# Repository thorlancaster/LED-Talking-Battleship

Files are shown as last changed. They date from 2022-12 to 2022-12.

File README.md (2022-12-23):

# LED-Talking-Battleship
Talking Battleship implemented on a 12x12 LED grid with an ATMega328 processor

This project is composed of:
* A Control PCB that contains the main circuitry and power supplies
* A LED display PCB that drives an 12x12 grid of RGB LEDs. You'll need to make 4 of these.
* Code to run the above boards
* A compiled audio file you'll need to write to the SPI Flash chip for audio functionality
 (If you leave the flash chip blank, the game will not play audio)

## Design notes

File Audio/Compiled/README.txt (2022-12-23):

Battleship.tatx should be copied byte for byte onto the SPI flash chip attached to the ATMega328.

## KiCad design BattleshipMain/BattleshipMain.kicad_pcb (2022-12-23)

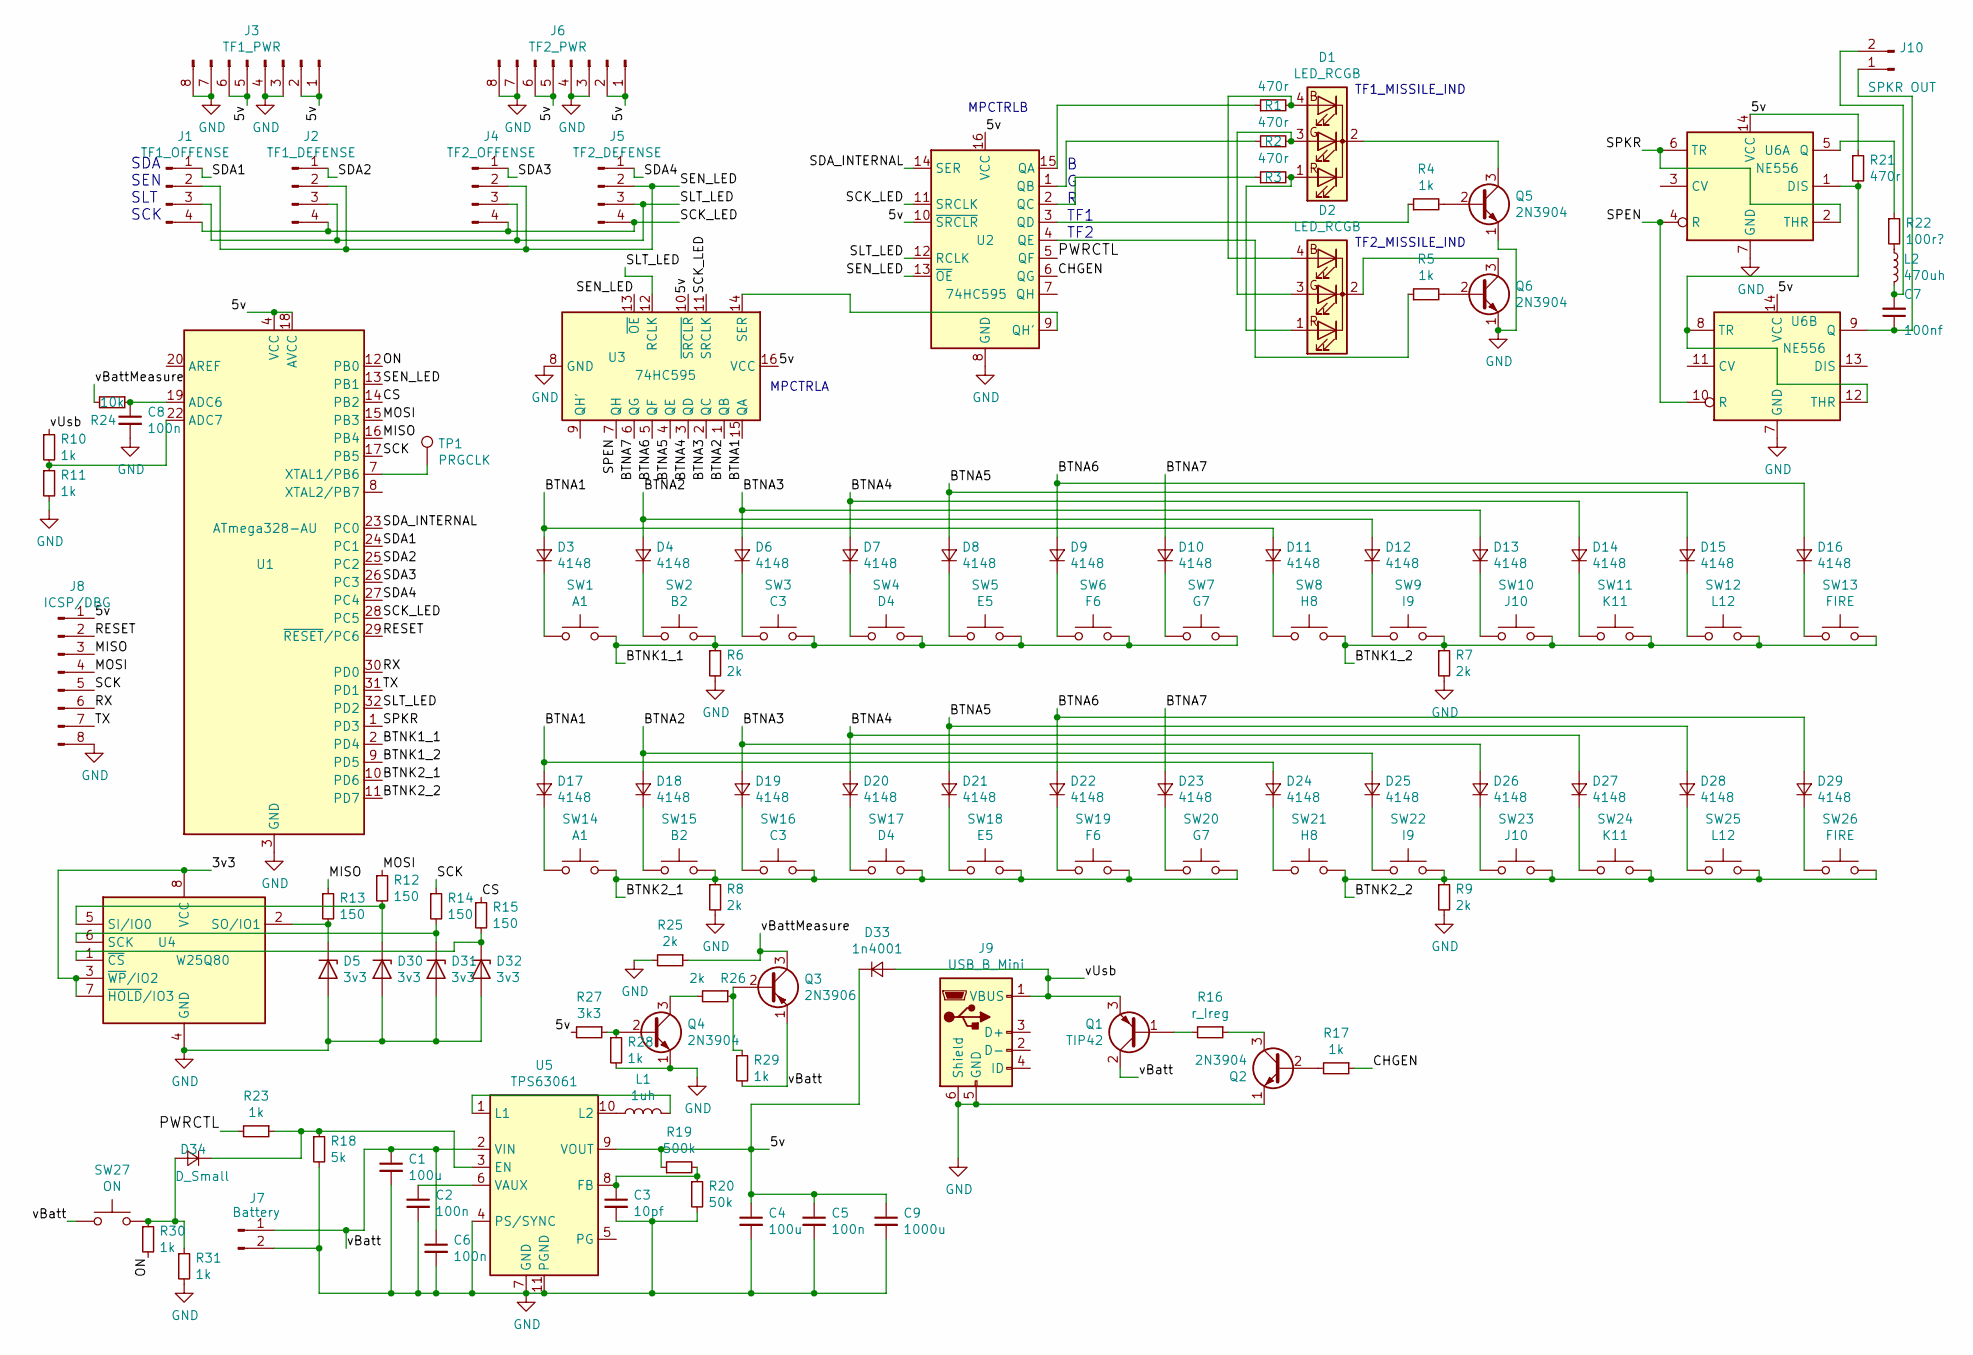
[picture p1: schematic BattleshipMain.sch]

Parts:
C1, C4: 100u; CP_Radial_D10.0mm_P2.50mm
C2, C5, C6, C8: 100n; C_0805_2012Metric
C3: 10pf; C_0805_2012Metric
C7: 100nf; C_0805_2012Metric
C9: 1000u; CP_Radial_D10.0mm_P7.50mm
D1, D2: LED_RCGB; LED_D5.0mm-4_RGB
D3, D4, D6, D7, D8, D9, D10, D11, D12, D13, D14, D15, D16, D17, D18, D19, D20, D21, D22, D23, D24, D25, D26, D27, D28, D29: 4148; D_DO-34_SOD68_P7.62mm_Horizontal
D5, D30, D31, D32: 3v3; D_DO-34_SOD68_P7.62mm_Horizontal
D33: 1n4001; D_DO-15_P10.16mm_Horizontal
D34: D_Small; D_DO-15_P10.16mm_Horizontal
J1: TF1_OFFENSE; PinHeader_1x04_P2.54mm_Vertical
J2: TF1_DEFENSE; PinHeader_1x04_P2.54mm_Vertical
J3: TF1_PWR; PinHeader_1x08_P2.54mm_Vertical
J4: TF2_OFFENSE; PinHeader_1x04_P2.54mm_Vertical
J5: TF2_DEFENSE; PinHeader_1x04_P2.54mm_Vertical
J6: TF2_PWR; PinHeader_1x08_P2.54mm_Vertical
J7: Battery; PinHeader_1x02_P2.54mm_Vertical
J8: ICSP/DBG; PinHeader_1x08_P2.54mm_Vertical
J9: USB_B_Mini; USB_Mini-B_Lumberg_2486_01_Horizontal
J10: SPKR OUT; PinHeader_1x02_P2.54mm_Vertical
L1: 1uh; L_Bourns-SRR1005
L2: 470uh; R_Axial_DIN0204_L3.6mm_D1.6mm_P7.62mm_Horizontal
Q1: TIP42; TO-220-3_Vertical
Q2, Q4, Q5, Q6: 2N3904; TO-92_Inline
Q3: 2N3906; TO-92_Inline
R1, R2, R3, R21: 470r; R_Axial_DIN0204_L3.6mm_D1.6mm_P7.62mm_Horizontal
R4, R5, R10, R11, R17, R23, R28, R29, R30, R31: 1k; R_Axial_DIN0207_L6.3mm_D2.5mm_P7.62mm_Horizontal
R6, R7, R8, R9, R25, R26: 2k; R_Axial_DIN0207_L6.3mm_D2.5mm_P7.62mm_Horizontal
R12, R13, R14, R15: 150; R_Axial_DIN0204_L3.6mm_D1.6mm_P7.62mm_Horizontal
R16: r_Ireg; R_Axial_DIN0207_L6.3mm_D2.5mm_P7.62mm_Horizontal
R18: 5k; R_Axial_DIN0207_L6.3mm_D2.5mm_P7.62mm_Horizontal
R19: 500k; R_Axial_DIN0207_L6.3mm_D2.5mm_P7.62mm_Horizontal
R20: 50k; R_Axial_DIN0207_L6.3mm_D2.5mm_P7.62mm_Horizontal
R22: 100r?; R_Axial_DIN0207_L6.3mm_D2.5mm_P7.62mm_Horizontal
R24: 10k; R_Axial_DIN0207_L6.3mm_D2.5mm_P7.62mm_Horizontal
R27: 3k3; R_Axial_DIN0207_L6.3mm_D2.5mm_P7.62mm_Horizontal
SW1, SW14: A1; Push_E-Switch_KS01Q01_RubberPad
SW2, SW15: B2; Push_E-Switch_KS01Q01_RubberPad
SW3, SW16: C3; Push_E-Switch_KS01Q01_RubberPad
SW4, SW17: D4; Push_E-Switch_KS01Q01_RubberPad
SW5, SW18: E5; Push_E-Switch_KS01Q01_RubberPad
SW6, SW19: F6; Push_E-Switch_KS01Q01_RubberPad
SW7, SW20: G7; Push_E-Switch_KS01Q01_RubberPad
SW8, SW21: H8; Push_E-Switch_KS01Q01_RubberPad
SW9, SW22: I9; Push_E-Switch_KS01Q01_RubberPad
SW10, SW23: J10; Push_E-Switch_KS01Q01_RubberPad
SW11, SW24: K11; Push_E-Switch_KS01Q01_RubberPad
SW12, SW25: L12; Push_E-Switch_KS01Q01_RubberPad
SW13, SW26: FIRE; Push_E-Switch_KS01Q01_RubberPad
SW27: ON; Push_E-Switch_KS01Q01_RubberPad
TP1: PRGCLK; TestPoint_Pad_2.5x2.5mm
U1: ATmega328-AU; TQFP-32_7x7mm_P0.8mm
U2, U3: 74HC595; DIP-16_W7.62mm
U4: W25Q80; SOIC-8_3.9x4.9mm_P1.27mm
U5: TPS63061; Texas_S-PWSON-N10_ThermalVias
U6: NE556; DIP-16_W7.62mm

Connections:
/3v3: U4.3 (~WP~/IO2), U4.7 (~HOLD~/IO3), U4.8 (VCC)
/5v: C4.1, C5.1, C9.1, D33.1 (K), J3.1, J3.2, J3.5, J3.6, J6.1, J6.2, J6.5, J6.6, J8.1, R19.1, R21.1, R27.2, U1.4 (VCC), U1.6 (VCC), U1.18 (AVCC), U2.10 (~SRCLR), U2.16 (VCC), U3.10 (~SRCLR), U3.16 (VCC), U5.9 (VOUT), U6.14 (VCC)
/BTNA1: D3.2 (A), D11.2 (A), D17.2 (A), D24.2 (A), U3.15 (QA)
/BTNA2: D4.2 (A), D12.2 (A), D18.2 (A), D25.2 (A), U3.1 (QB)
/BTNA3: D6.2 (A), D13.2 (A), D19.2 (A), D26.2 (A), U3.2 (QC)
/BTNA4: D7.2 (A), D14.2 (A), D20.2 (A), D27.2 (A), U3.3 (QD)
/BTNA5: D8.2 (A), D15.2 (A), D21.2 (A), D28.2 (A), U3.4 (QE)
/BTNA6: D9.2 (A), D16.2 (A), D22.2 (A), D29.2 (A), U3.5 (QF)
/BTNA7: D10.2 (A), D23.2 (A), U3.6 (QG)
/BTNK1_1: R6.1, SW1.2, SW2.2, SW3.2, SW4.2, SW5.2, SW6.2, SW7.2, U1.2 (PD4)
/BTNK1_2: R7.1, SW8.2, SW9.2, SW10.2, SW11.2, SW12.2, SW13.2, U1.9 (PD5)
/BTNK2_1: R8.1, SW14.2, SW15.2, SW16.2, SW17.2, SW18.2, SW19.2, SW20.2, U1.10 (PD6)
/BTNK2_2: R9.1, SW21.2, SW22.2, SW23.2, SW24.2, SW25.2, SW26.2, U1.11 (PD7)
/CS: R15.1, U1.14 (PB2)
/MISO: J8.3, R13.1, U1.16 (PB4)
/MOSI: J8.4, R12.1, U1.15 (PB3)
/ON: R30.2, U1.12 (PB0)
/RESET: J8.2, U1.29 (~RESET~/PC6)
/RX: J8.6, U1.30 (PD0)
/SCK: J8.5, R14.1, U1.17 (PB5)
/SDA1: J1.1, U1.24 (PC1)
/SDA2: J2.1, U1.25 (PC2)
/SDA3: J4.1, U1.26 (PC3)
/SDA4: J5.1, U1.27 (PC4)
/SDA_INTERNAL: U1.23 (PC0), U2.14 (SER)
/SEN_LED: J1.2, J2.2, J4.2, J5.2, U1.13 (PB1), U2.13 (~OE), U3.13 (~OE)
/SPEN: U3.7 (QH), U6.4 (R), U6.10 (R)
/SPKR: U1.1 (PD3), U6.2 (THR), U6.6 (TR)
/TX: J8.7, U1.31 (PD1)
/vBatt: C1.1, C6.1, J7.1, Q1.2 (C), Q3.1 (E), R29.2, SW27.1, U5.2 (VIN)
/vBattMeasure: Q3.3 (C), R24.2, R25.1
/vUsb: D33.2 (A), J9.1 (VBUS), Q1.3 (E), R10.1
GND: C1.2, C2.2, C3.2, C4.2, C5.2, C6.2, C8.2, C9.2, D5.2 (A), D30.2 (A), D31.2 (A), D32.2 (A), J3.3, J3.4, J3.7, J3.8, J6.3, J6.4, J6.7, J6.8, J7.2, J8.8, J9.5 (GND), J9.6 (Shield), Q2.1 (E), Q4.1 (E), Q5.1 (E), Q6.1 (E), R6.2, R7.2, R8.2, R9.2, R11.2, R18.2, R20.2, R25.2, R28.2, R31.2, U1.3 (GND), U1.5 (GND), U1.21 (GND), U2.8 (GND), U3.8 (GND), U4.4 (GND), U5.4 (PS/SYNC), U5.7 (GND), U5.11 (PGND), U6.7 (GND)
unnamed: C2.1, U5.6 (VAUX)
unnamed: C3.1, R19.2, R20.1, U5.8 (FB)
unnamed: C7.1, J10.1, U6.9 (Q)
unnamed: C7.2, J10.2, L2.2
unnamed: C8.1, R24.1, U1.19 (ADC6)
unnamed: D1.1 (RA), D2.1 (RA), R3.2
unnamed: D1.2 (K), Q5.3 (C)
unnamed: D1.3 (GA), D2.3 (GA), R2.2
unnamed: D1.4 (BA), D2.4 (BA), R1.2
unnamed: D2.2 (K), Q6.3 (C)
unnamed: D3.1 (K), SW1.1
unnamed: D4.1 (K), SW2.1
unnamed: D5.1 (K), R13.2, U4.2 (SO/IO1)
unnamed: D6.1 (K), SW3.1
unnamed: D7.1 (K), SW4.1
unnamed: D8.1 (K), SW5.1
unnamed: D9.1 (K), SW6.1
unnamed: D10.1 (K), SW7.1
unnamed: D11.1 (K), SW8.1
unnamed: D12.1 (K), SW9.1
unnamed: D13.1 (K), SW10.1
unnamed: D14.1 (K), SW11.1
unnamed: D15.1 (K), SW12.1
unnamed: D16.1 (K), SW13.1
unnamed: D17.1 (K), SW14.1
unnamed: D18.1 (K), SW15.1
unnamed: D19.1 (K), SW16.1
unnamed: D20.1 (K), SW17.1
unnamed: D21.1 (K), SW18.1
unnamed: D22.1 (K), SW19.1
unnamed: D23.1 (K), SW20.1
unnamed: D24.1 (K), SW21.1
unnamed: D25.1 (K), SW22.1
unnamed: D26.1 (K), SW23.1
unnamed: D27.1 (K), SW24.1
unnamed: D28.1 (K), SW25.1
unnamed: D29.1 (K), SW26.1
unnamed: D30.1 (K), R12.2, U4.5 (SI/IO0)
unnamed: D31.1 (K), R14.2, U4.6 (SCK)
unnamed: D32.1 (K), R15.2, U4.1 (~CS)
unnamed: D34.1 (K), R18.1, R23.1, U5.3 (EN)
unnamed: D34.2 (A), R30.1, R31.1, SW27.2
unnamed: L1.1, U5.10 (L2)
unnamed: L1.2, U5.1 (L1)
unnamed: L2.1, R22.2
unnamed: Q1.1 (B), R16.2
unnamed: Q2.2 (B), R17.2
unnamed: Q2.3 (C), R16.1
unnamed: Q3.2 (B), R26.1, R29.1
unnamed: Q4.2 (B), R27.1, R28.1
unnamed: Q4.3 (C), R26.2
unnamed: Q5.2 (B), R4.2
unnamed: Q6.2 (B), R5.2
unnamed: R1.1, U2.15 (QA)
unnamed: R2.1, U2.1 (QB)
unnamed: R3.1, U2.2 (QC)
unnamed: R4.1, U2.3 (QD)
unnamed: R5.1, U2.4 (QE)
unnamed: R10.2, R11.1, U1.22 (ADC7)
unnamed: R21.2, U6.1 (DIS), U6.8 (TR), U6.12 (THR)
unnamed: R22.1, U6.5 (Q)
unnamed: U2.9 (QH'), U3.14 (SER)

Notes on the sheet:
SDA SEN SLT SCK
TF1_MISSILE_IND
TF2_MISSILE_IND
B G R TF1 TF2
MPCTRLB
MPCTRLA

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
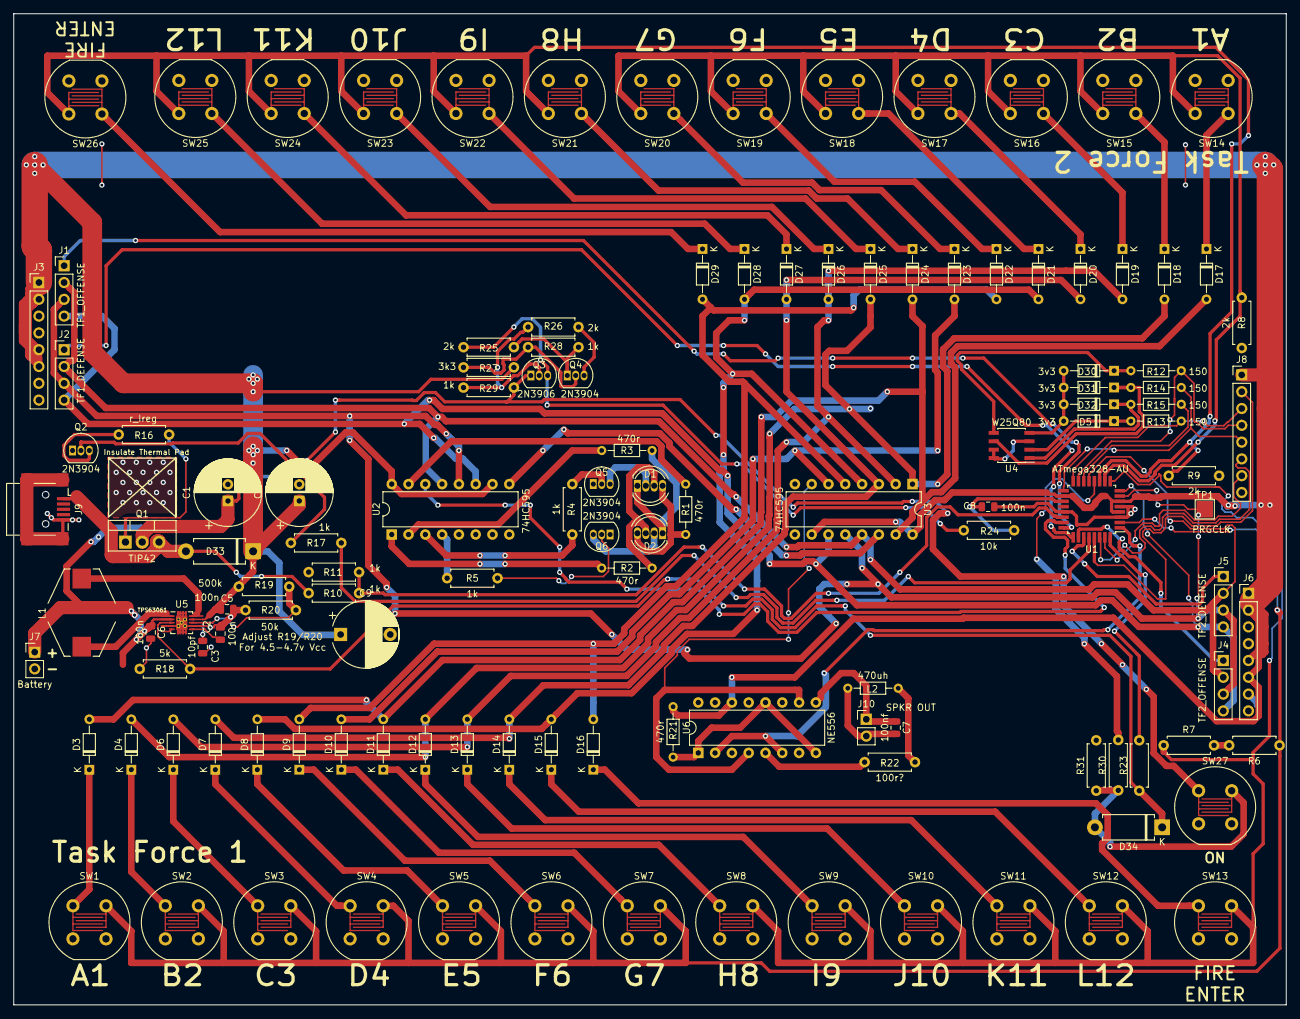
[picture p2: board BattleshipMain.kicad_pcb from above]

Board: 2 copper layers, 192.4 x 149.9 mm, 126 parts (0 on the bottom side), 99 nets.

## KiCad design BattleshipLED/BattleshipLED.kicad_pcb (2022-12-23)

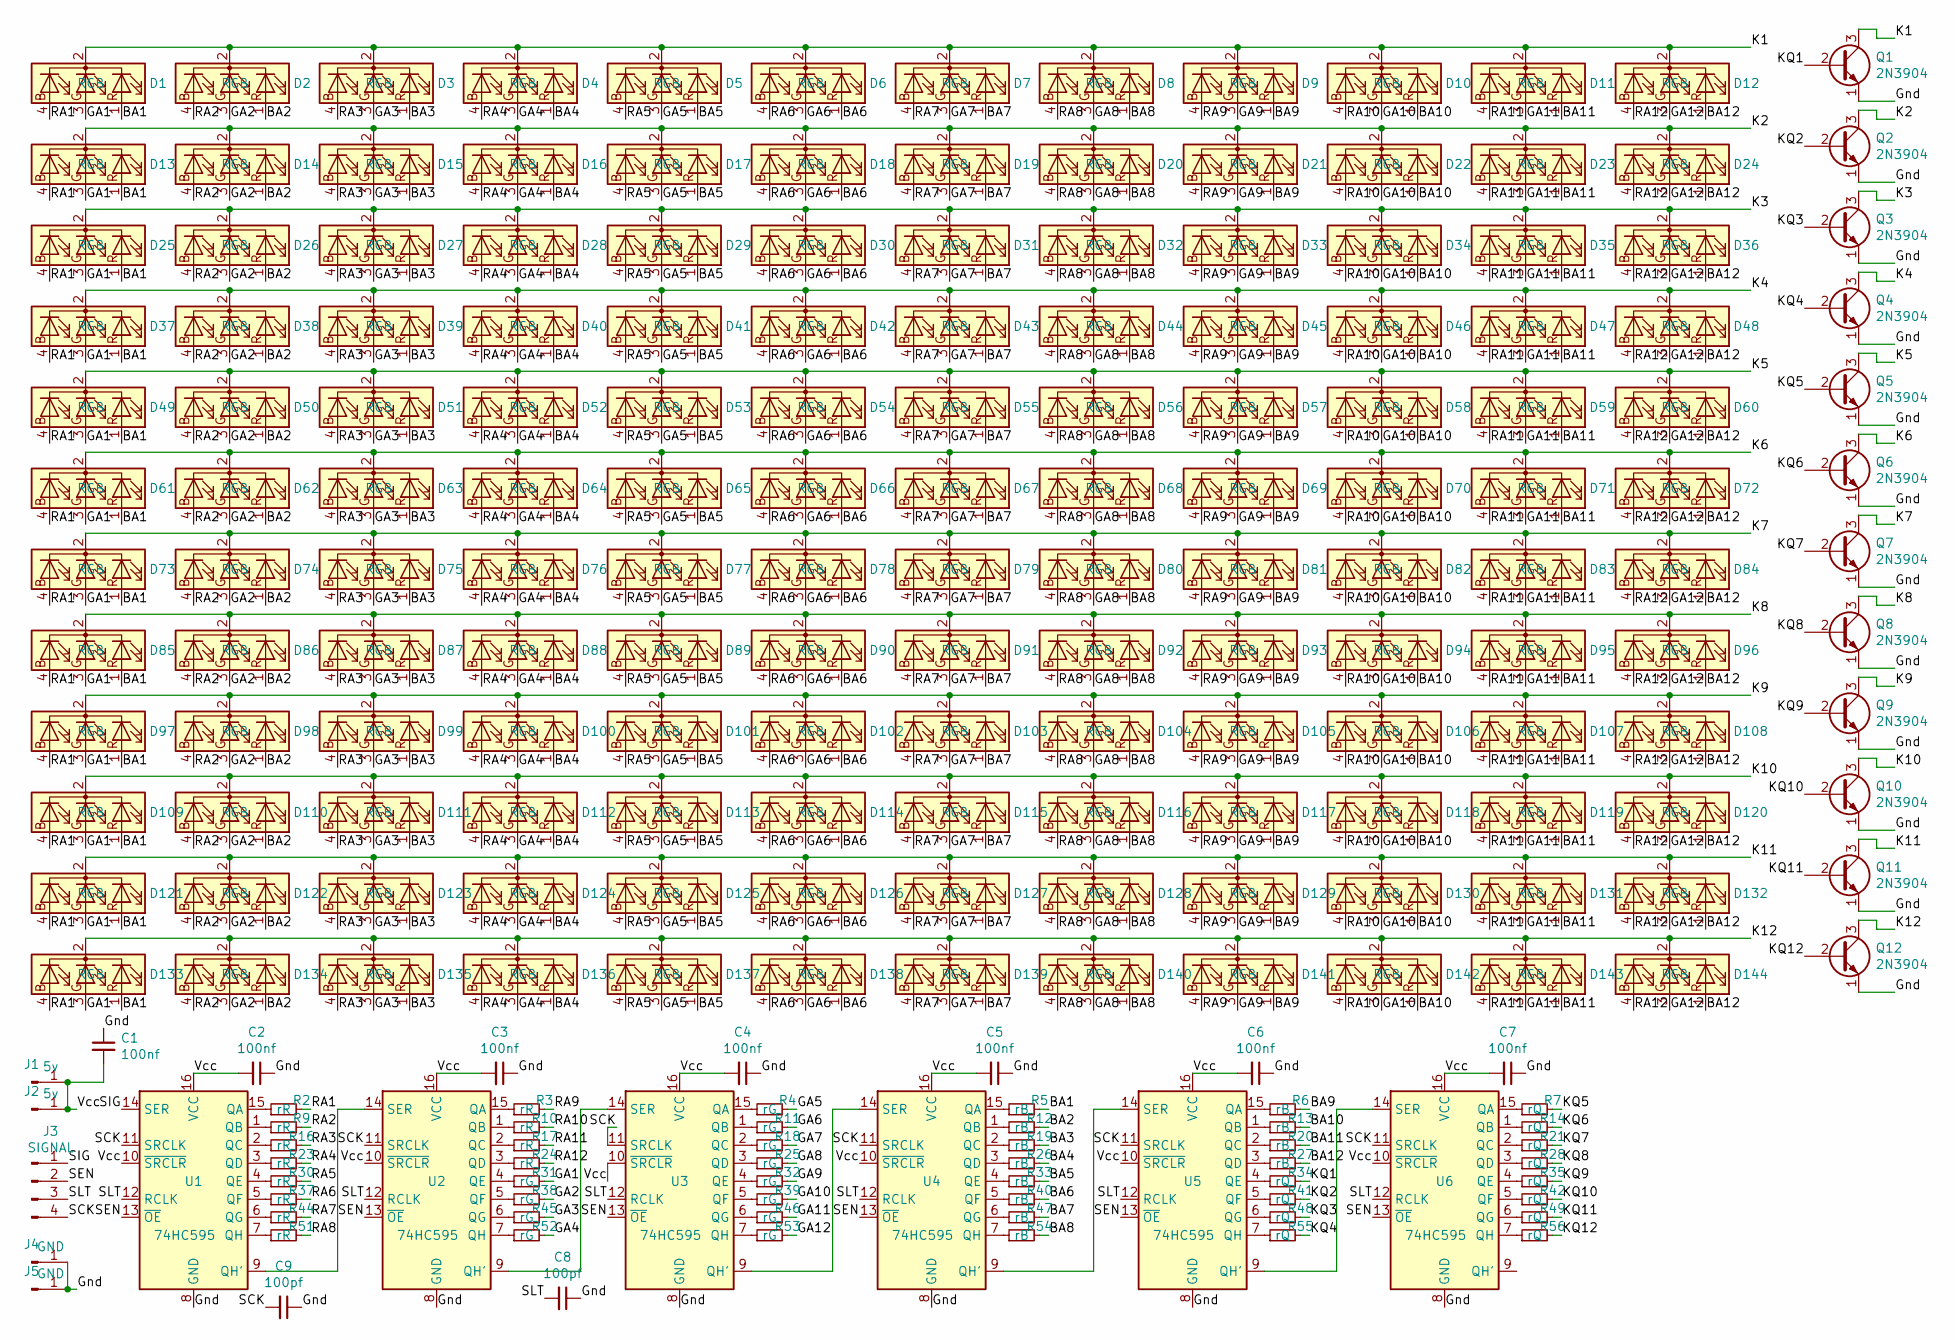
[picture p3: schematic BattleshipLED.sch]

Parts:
C1, C2, C3, C4, C5, C6, C7: 100nf; C_0805_2012Metric
C8, C9: 100pf; C_0805_2012Metric
D1, D2, D3, D4, D5, D6, D7, D8, D9, D10, D11, D12, D13, D14, D15, D16, D17, D18, D19, D20, D21, D22, D23, D24, D25, D26, D27, D28, D29, D30, D31, D32, D33, D34, D35, D36, D37, D38, D39, D40, D41, D42, D43, D44, D45, D46, D47, D48, D49, D50, D51, D52, D53, D54, D55, D56, D57, D58, D59, D60, D61, D62, D63, D64, D65, D66, D67, D68, D69, D70, D71, D72, D73, D74, D75, D76, D77, D78, D79, D80, D81, D82, D83, D84, D85, D86, D87, D88, D89, D90, D91, D92, D93, D94, D95, D96, D97, D98, D99, D100, D101, D102, D103, D104, D105, D106, D107, D108, D109, D110, D111, D112, D113, D114, D115, D116, D117, D118, D119, D120, D121, D122, D123, D124, D125, D126, D127, D128, D129, D130, D131, D132, D133, D134, D135, D136, D137, D138, D139, D140, D141, D142, D143, D144: RGB; LED_D5.0mm-4_RGB
J1, J2: 5v; PinHeader_1x01_P2.54mm_Vertical
J3: SIGNAL; PinHeader_1x04_P2.54mm_Vertical
J4, J5: GND; PinHeader_1x01_P2.54mm_Vertical
Q1, Q2, Q3, Q4, Q5, Q6, Q7, Q8, Q9, Q10, Q11, Q12: 2N3904; TO-92_Inline
R2, R3, R9, R10, R16, R17, R23, R24, R30, R37, R44, R51: rR; R_Axial_DIN0204_L3.6mm_D1.6mm_P7.62mm_Horizontal
R4, R11, R18, R25, R31, R32, R38, R39, R45, R46, R52, R53: rG; R_Axial_DIN0204_L3.6mm_D1.6mm_P7.62mm_Horizontal
R5, R6, R12, R13, R19, R20, R26, R27, R33, R40, R47, R54: rB; R_Axial_DIN0204_L3.6mm_D1.6mm_P7.62mm_Horizontal
R7, R14, R21, R28, R34, R35, R41, R42, R48, R49, R55, R56: rQ; R_Axial_DIN0204_L3.6mm_D1.6mm_P7.62mm_Horizontal
U1, U2, U3, U4, U5, U6: 74HC595; DIP-16_W7.62mm

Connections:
/BA1: D1.1 (RA), D13.1 (RA), D25.1 (RA), D37.1 (RA), D49.1 (RA), D61.1 (RA), D73.1 (RA), D85.1 (RA), D97.1 (RA), D109.1 (RA), D121.1 (RA), D133.1 (RA), R5.2
/BA2: D2.1 (RA), D14.1 (RA), D26.1 (RA), D38.1 (RA), D50.1 (RA), D62.1 (RA), D74.1 (RA), D86.1 (RA), D98.1 (RA), D110.1 (RA), D122.1 (RA), D134.1 (RA), R12.2
/BA3: D3.1 (RA), D15.1 (RA), D27.1 (RA), D39.1 (RA), D51.1 (RA), D63.1 (RA), D75.1 (RA), D87.1 (RA), D99.1 (RA), D111.1 (RA), D123.1 (RA), D135.1 (RA), R19.2
/BA4: D4.1 (RA), D16.1 (RA), D28.1 (RA), D40.1 (RA), D52.1 (RA), D64.1 (RA), D76.1 (RA), D88.1 (RA), D100.1 (RA), D112.1 (RA), D124.1 (RA), D136.1 (RA), R26.2
/BA5: D5.1 (RA), D17.1 (RA), D29.1 (RA), D41.1 (RA), D53.1 (RA), D65.1 (RA), D77.1 (RA), D89.1 (RA), D101.1 (RA), D113.1 (RA), D125.1 (RA), D137.1 (RA), R33.2
/BA6: D6.1 (RA), D18.1 (RA), D30.1 (RA), D42.1 (RA), D54.1 (RA), D66.1 (RA), D78.1 (RA), D90.1 (RA), D102.1 (RA), D114.1 (RA), D126.1 (RA), D138.1 (RA), R40.2
/BA7: D7.1 (RA), D19.1 (RA), D31.1 (RA), D43.1 (RA), D55.1 (RA), D67.1 (RA), D79.1 (RA), D91.1 (RA), D103.1 (RA), D115.1 (RA), D127.1 (RA), D139.1 (RA), R47.2
/BA8: D8.1 (RA), D20.1 (RA), D32.1 (RA), D44.1 (RA), D56.1 (RA), D68.1 (RA), D80.1 (RA), D92.1 (RA), D104.1 (RA), D116.1 (RA), D128.1 (RA), D140.1 (RA), R54.2
/BA9: D9.1 (RA), D21.1 (RA), D33.1 (RA), D45.1 (RA), D57.1 (RA), D69.1 (RA), D81.1 (RA), D93.1 (RA), D105.1 (RA), D117.1 (RA), D129.1 (RA), D141.1 (RA), R6.2
/BA10: D10.1 (RA), D22.1 (RA), D34.1 (RA), D46.1 (RA), D58.1 (RA), D70.1 (RA), D82.1 (RA), D94.1 (RA), D106.1 (RA), D118.1 (RA), D130.1 (RA), D142.1 (RA), R13.2
/BA11: D11.1 (RA), D23.1 (RA), D35.1 (RA), D47.1 (RA), D59.1 (RA), D71.1 (RA), D83.1 (RA), D95.1 (RA), D107.1 (RA), D119.1 (RA), D131.1 (RA), D143.1 (RA), R20.2
/BA12: D12.1 (RA), D24.1 (RA), D36.1 (RA), D48.1 (RA), D60.1 (RA), D72.1 (RA), D84.1 (RA), D96.1 (RA), D108.1 (RA), D120.1 (RA), D132.1 (RA), D144.1 (RA), R27.2
/GA1: D1.3 (GA), D13.3 (GA), D25.3 (GA), D37.3 (GA), D49.3 (GA), D61.3 (GA), D73.3 (GA), D85.3 (GA), D97.3 (GA), D109.3 (GA), D121.3 (GA), D133.3 (GA), R31.2
/GA2: D2.3 (GA), D14.3 (GA), D26.3 (GA), D38.3 (GA), D50.3 (GA), D62.3 (GA), D74.3 (GA), D86.3 (GA), D98.3 (GA), D110.3 (GA), D122.3 (GA), D134.3 (GA), R38.2
/GA3: D3.3 (GA), D15.3 (GA), D27.3 (GA), D39.3 (GA), D51.3 (GA), D63.3 (GA), D75.3 (GA), D87.3 (GA), D99.3 (GA), D111.3 (GA), D123.3 (GA), D135.3 (GA), R45.2
/GA4: D4.3 (GA), D16.3 (GA), D28.3 (GA), D40.3 (GA), D52.3 (GA), D64.3 (GA), D76.3 (GA), D88.3 (GA), D100.3 (GA), D112.3 (GA), D124.3 (GA), D136.3 (GA), R52.2
/GA5: D5.3 (GA), D17.3 (GA), D29.3 (GA), D41.3 (GA), D53.3 (GA), D65.3 (GA), D77.3 (GA), D89.3 (GA), D101.3 (GA), D113.3 (GA), D125.3 (GA), D137.3 (GA), R4.2
/GA6: D6.3 (GA), D18.3 (GA), D30.3 (GA), D42.3 (GA), D54.3 (GA), D66.3 (GA), D78.3 (GA), D90.3 (GA), D102.3 (GA), D114.3 (GA), D126.3 (GA), D138.3 (GA), R11.2
/GA7: D7.3 (GA), D19.3 (GA), D31.3 (GA), D43.3 (GA), D55.3 (GA), D67.3 (GA), D79.3 (GA), D91.3 (GA), D103.3 (GA), D115.3 (GA), D127.3 (GA), D139.3 (GA), R18.2
/GA8: D8.3 (GA), D20.3 (GA), D32.3 (GA), D44.3 (GA), D56.3 (GA), D68.3 (GA), D80.3 (GA), D92.3 (GA), D104.3 (GA), D116.3 (GA), D128.3 (GA), D140.3 (GA), R25.2
/GA9: D9.3 (GA), D21.3 (GA), D33.3 (GA), D45.3 (GA), D57.3 (GA), D69.3 (GA), D81.3 (GA), D93.3 (GA), D105.3 (GA), D117.3 (GA), D129.3 (GA), D141.3 (GA), R32.2
/GA10: D10.3 (GA), D22.3 (GA), D34.3 (GA), D46.3 (GA), D58.3 (GA), D70.3 (GA), D82.3 (GA), D94.3 (GA), D106.3 (GA), D118.3 (GA), D130.3 (GA), D142.3 (GA), R39.2
/GA11: D11.3 (GA), D23.3 (GA), D35.3 (GA), D47.3 (GA), D59.3 (GA), D71.3 (GA), D83.3 (GA), D95.3 (GA), D107.3 (GA), D119.3 (GA), D131.3 (GA), D143.3 (GA), R46.2
/GA12: D12.3 (GA), D24.3 (GA), D36.3 (GA), D48.3 (GA), D60.3 (GA), D72.3 (GA), D84.3 (GA), D96.3 (GA), D108.3 (GA), D120.3 (GA), D132.3 (GA), D144.3 (GA), R53.2
/Gnd: C1.1, C2.1, C3.1, C4.1, C5.1, C6.1, C7.1, C8.1, C9.1, J4.1, J5.1, Q1.1 (E), Q2.1 (E), Q3.1 (E), Q4.1 (E), Q5.1 (E), Q6.1 (E), Q7.1 (E), Q8.1 (E), Q9.1 (E), Q10.1 (E), Q11.1 (E), Q12.1 (E), U1.8 (GND), U2.8 (GND), U3.8 (GND), U4.8 (GND), U5.8 (GND), U6.8 (GND)
/K1: D1.2 (K), D2.2 (K), D3.2 (K), D4.2 (K), D5.2 (K), D6.2 (K), D7.2 (K), D8.2 (K), D9.2 (K), D10.2 (K), D11.2 (K), D12.2 (K), Q1.3 (C)
/K2: D13.2 (K), D14.2 (K), D15.2 (K), D16.2 (K), D17.2 (K), D18.2 (K), D19.2 (K), D20.2 (K), D21.2 (K), D22.2 (K), D23.2 (K), D24.2 (K), Q2.3 (C)
/K3: D25.2 (K), D26.2 (K), D27.2 (K), D28.2 (K), D29.2 (K), D30.2 (K), D31.2 (K), D32.2 (K), D33.2 (K), D34.2 (K), D35.2 (K), D36.2 (K), Q3.3 (C)
/K4: D37.2 (K), D38.2 (K), D39.2 (K), D40.2 (K), D41.2 (K), D42.2 (K), D43.2 (K), D44.2 (K), D45.2 (K), D46.2 (K), D47.2 (K), D48.2 (K), Q4.3 (C)
/K5: D49.2 (K), D50.2 (K), D51.2 (K), D52.2 (K), D53.2 (K), D54.2 (K), D55.2 (K), D56.2 (K), D57.2 (K), D58.2 (K), D59.2 (K), D60.2 (K), Q5.3 (C)
/K6: D61.2 (K), D62.2 (K), D63.2 (K), D64.2 (K), D65.2 (K), D66.2 (K), D67.2 (K), D68.2 (K), D69.2 (K), D70.2 (K), D71.2 (K), D72.2 (K), Q6.3 (C)
/K7: D73.2 (K), D74.2 (K), D75.2 (K), D76.2 (K), D77.2 (K), D78.2 (K), D79.2 (K), D80.2 (K), D81.2 (K), D82.2 (K), D83.2 (K), D84.2 (K), Q7.3 (C)
/K8: D85.2 (K), D86.2 (K), D87.2 (K), D88.2 (K), D89.2 (K), D90.2 (K), D91.2 (K), D92.2 (K), D93.2 (K), D94.2 (K), D95.2 (K), D96.2 (K), Q8.3 (C)
/K9: D97.2 (K), D98.2 (K), D99.2 (K), D100.2 (K), D101.2 (K), D102.2 (K), D103.2 (K), D104.2 (K), D105.2 (K), D106.2 (K), D107.2 (K), D108.2 (K), Q9.3 (C)
/K10: D109.2 (K), D110.2 (K), D111.2 (K), D112.2 (K), D113.2 (K), D114.2 (K), D115.2 (K), D116.2 (K), D117.2 (K), D118.2 (K), D119.2 (K), D120.2 (K), Q10.3 (C)
/K11: D121.2 (K), D122.2 (K), D123.2 (K), D124.2 (K), D125.2 (K), D126.2 (K), D127.2 (K), D128.2 (K), D129.2 (K), D130.2 (K), D131.2 (K), D132.2 (K), Q11.3 (C)
/K12: D133.2 (K), D134.2 (K), D135.2 (K), D136.2 (K), D137.2 (K), D138.2 (K), D139.2 (K), D140.2 (K), D141.2 (K), D142.2 (K), D143.2 (K), D144.2 (K), Q12.3 (C)
/KQ1: Q1.2 (B), R34.2
/KQ2: Q2.2 (B), R41.2
/KQ3: Q3.2 (B), R48.2
/KQ4: Q4.2 (B), R55.2
/KQ5: Q5.2 (B), R7.2
/KQ6: Q6.2 (B), R14.2
/KQ7: Q7.2 (B), R21.2
/KQ8: Q8.2 (B), R28.2
/KQ9: Q9.2 (B), R35.2
/KQ10: Q10.2 (B), R42.2
/KQ11: Q11.2 (B), R49.2
/KQ12: Q12.2 (B), R56.2
/RA1: D1.4 (BA), D13.4 (BA), D25.4 (BA), D37.4 (BA), D49.4 (BA), D61.4 (BA), D73.4 (BA), D85.4 (BA), D97.4 (BA), D109.4 (BA), D121.4 (BA), D133.4 (BA), R2.2
/RA2: D2.4 (BA), D14.4 (BA), D26.4 (BA), D38.4 (BA), D50.4 (BA), D62.4 (BA), D74.4 (BA), D86.4 (BA), D98.4 (BA), D110.4 (BA), D122.4 (BA), D134.4 (BA), R9.2
/RA3: D3.4 (BA), D15.4 (BA), D27.4 (BA), D39.4 (BA), D51.4 (BA), D63.4 (BA), D75.4 (BA), D87.4 (BA), D99.4 (BA), D111.4 (BA), D123.4 (BA), D135.4 (BA), R16.2
/RA4: D4.4 (BA), D16.4 (BA), D28.4 (BA), D40.4 (BA), D52.4 (BA), D64.4 (BA), D76.4 (BA), D88.4 (BA), D100.4 (BA), D112.4 (BA), D124.4 (BA), D136.4 (BA), R23.2
/RA5: D5.4 (BA), D17.4 (BA), D29.4 (BA), D41.4 (BA), D53.4 (BA), D65.4 (BA), D77.4 (BA), D89.4 (BA), D101.4 (BA), D113.4 (BA), D125.4 (BA), D137.4 (BA), R30.2
/RA6: D6.4 (BA), D18.4 (BA), D30.4 (BA), D42.4 (BA), D54.4 (BA), D66.4 (BA), D78.4 (BA), D90.4 (BA), D102.4 (BA), D114.4 (BA), D126.4 (BA), D138.4 (BA), R37.2
/RA7: D7.4 (BA), D19.4 (BA), D31.4 (BA), D43.4 (BA), D55.4 (BA), D67.4 (BA), D79.4 (BA), D91.4 (BA), D103.4 (BA), D115.4 (BA), D127.4 (BA), D139.4 (BA), R44.2
/RA8: D8.4 (BA), D20.4 (BA), D32.4 (BA), D44.4 (BA), D56.4 (BA), D68.4 (BA), D80.4 (BA), D92.4 (BA), D104.4 (BA), D116.4 (BA), D128.4 (BA), D140.4 (BA), R51.2
/RA9: D9.4 (BA), D21.4 (BA), D33.4 (BA), D45.4 (BA), D57.4 (BA), D69.4 (BA), D81.4 (BA), D93.4 (BA), D105.4 (BA), D117.4 (BA), D129.4 (BA), D141.4 (BA), R3.2
/RA10: D10.4 (BA), D22.4 (BA), D34.4 (BA), D46.4 (BA), D58.4 (BA), D70.4 (BA), D82.4 (BA), D94.4 (BA), D106.4 (BA), D118.4 (BA), D130.4 (BA), D142.4 (BA), R10.2
/RA11: D11.4 (BA), D23.4 (BA), D35.4 (BA), D47.4 (BA), D59.4 (BA), D71.4 (BA), D83.4 (BA), D95.4 (BA), D107.4 (BA), D119.4 (BA), D131.4 (BA), D143.4 (BA), R17.2
/RA12: D12.4 (BA), D24.4 (BA), D36.4 (BA), D48.4 (BA), D60.4 (BA), D72.4 (BA), D84.4 (BA), D96.4 (BA), D108.4 (BA), D120.4 (BA), D132.4 (BA), D144.4 (BA), R24.2
/SCK: C9.2, J3.4, U1.11 (SRCLK), U2.11 (SRCLK), U3.11 (SRCLK), U4.11 (SRCLK), U5.11 (SRCLK), U6.11 (SRCLK)
/SEN: J3.2, U1.13 (~OE), U2.13 (~OE), U3.13 (~OE), U4.13 (~OE), U5.13 (~OE), U6.13 (~OE)
/SIG: J3.1, U1.14 (SER)
/SLT: C8.2, J3.3, U1.12 (RCLK), U2.12 (RCLK), U3.12 (RCLK), U4.12 (RCLK), U5.12 (RCLK), U6.12 (RCLK)
/Vcc: C1.2, C2.2, C3.2, C4.2, C5.2, C6.2, C7.2, J1.1, J2.1, U1.10 (~SRCLR), U1.16 (VCC), U2.10 (~SRCLR), U2.16 (VCC), U3.10 (~SRCLR), U3.16 (VCC), U4.10 (~SRCLR), U4.16 (VCC), U5.10 (~SRCLR), U5.16 (VCC), U6.10 (~SRCLR), U6.16 (VCC)
unnamed: R2.1, U1.15 (QA)
unnamed: R3.1, U2.15 (QA)
unnamed: R4.1, U3.15 (QA)
unnamed: R5.1, U4.15 (QA)
unnamed: R6.1, U5.15 (QA)
unnamed: R7.1, U6.15 (QA)
unnamed: R9.1, U1.1 (QB)
unnamed: R10.1, U2.1 (QB)
unnamed: R11.1, U3.1 (QB)
unnamed: R12.1, U4.1 (QB)
unnamed: R13.1, U5.1 (QB)
unnamed: R14.1, U6.1 (QB)
unnamed: R16.1, U1.2 (QC)
unnamed: R17.1, U2.2 (QC)
unnamed: R18.1, U3.2 (QC)
unnamed: R19.1, U4.2 (QC)
unnamed: R20.1, U5.2 (QC)
unnamed: R21.1, U6.2 (QC)
unnamed: R23.1, U1.3 (QD)
unnamed: R24.1, U2.3 (QD)
unnamed: R25.1, U3.3 (QD)
unnamed: R26.1, U4.3 (QD)
unnamed: R27.1, U5.3 (QD)
unnamed: R28.1, U6.3 (QD)
unnamed: R30.1, U1.4 (QE)
unnamed: R31.1, U2.4 (QE)
unnamed: R32.1, U3.4 (QE)
unnamed: R33.1, U4.4 (QE)
unnamed: R34.1, U5.4 (QE)
unnamed: R35.1, U6.4 (QE)
unnamed: R37.1, U1.5 (QF)
unnamed: R38.1, U2.5 (QF)
unnamed: R39.1, U3.5 (QF)
unnamed: R40.1, U4.5 (QF)
unnamed: R41.1, U5.5 (QF)
unnamed: R42.1, U6.5 (QF)
unnamed: R44.1, U1.6 (QG)
unnamed: R45.1, U2.6 (QG)
unnamed: R46.1, U3.6 (QG)
unnamed: R47.1, U4.6 (QG)
unnamed: R48.1, U5.6 (QG)
unnamed: R49.1, U6.6 (QG)
unnamed: R51.1, U1.7 (QH)
unnamed: R52.1, U2.7 (QH)
unnamed: R53.1, U3.7 (QH)
unnamed: R54.1, U4.7 (QH)
unnamed: R55.1, U5.7 (QH)
unnamed: R56.1, U6.7 (QH)
unnamed: U1.9 (QH'), U2.14 (SER)
unnamed: U2.9 (QH'), U3.14 (SER)
unnamed: U3.9 (QH'), U4.14 (SER)
unnamed: U4.9 (QH'), U5.14 (SER)
unnamed: U5.9 (QH'), U6.14 (SER)

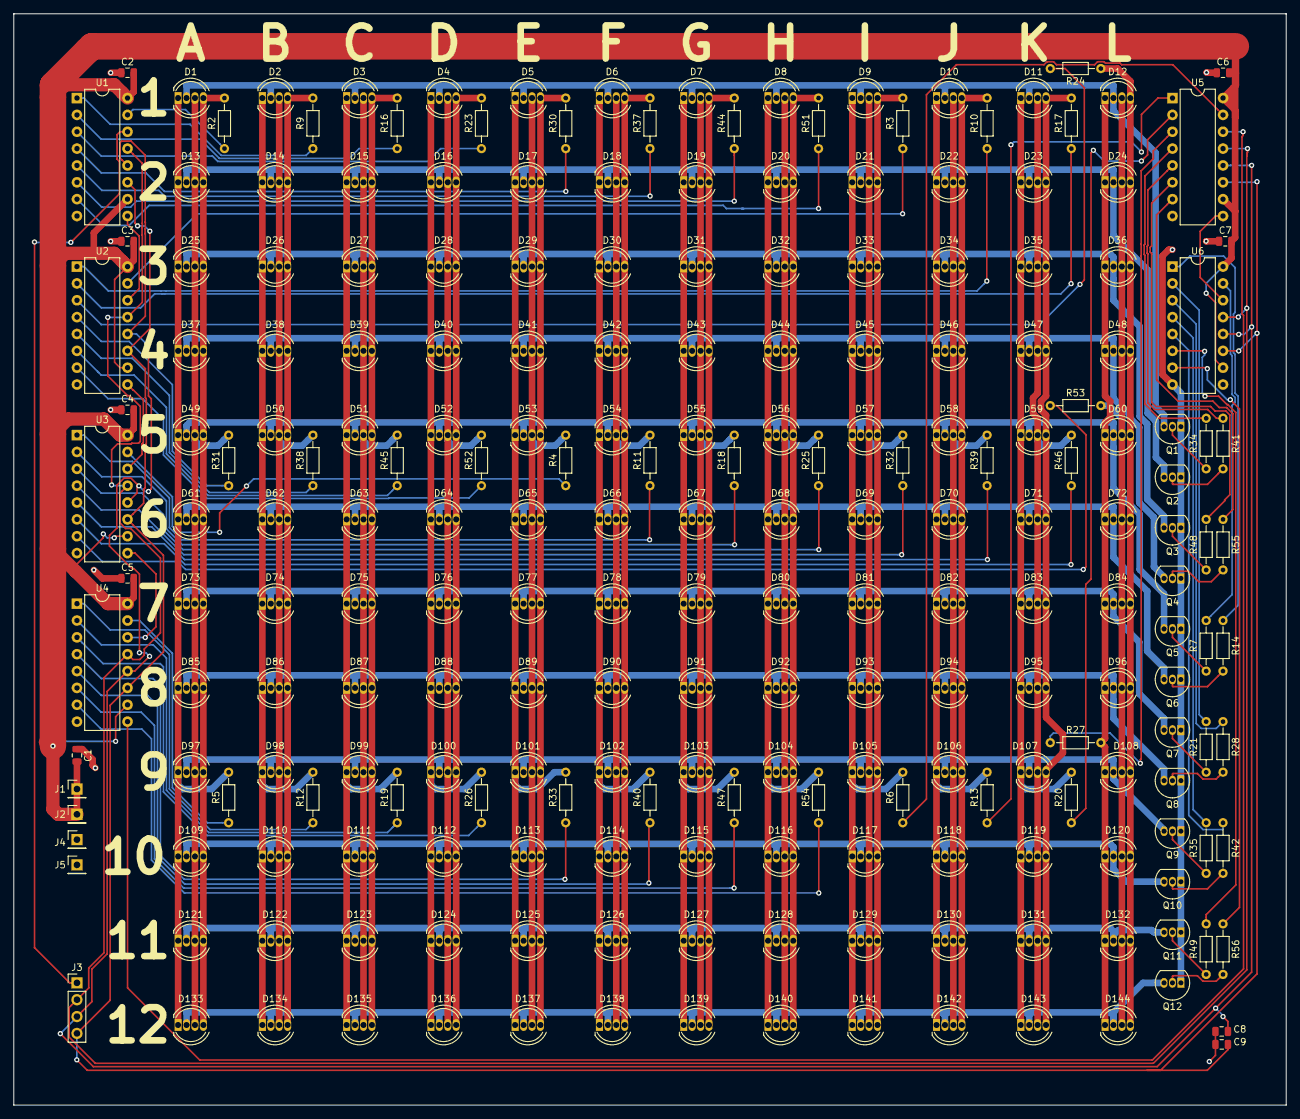
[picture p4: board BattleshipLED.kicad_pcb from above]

Board: 2 copper layers, 191.8 x 164.5 mm, 224 parts (0 on the bottom side), 119 nets.

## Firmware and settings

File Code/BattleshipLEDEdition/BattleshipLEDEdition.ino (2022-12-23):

#include <AsyncAnalog.h>

#include <SPI.h>
#define delay Delay
#define SERIAL_TX_BUFFER_SIZE 32
#define SERIAL_RX_BUFFER_SIZE 32 // 64 more bytes for us! We really need them.

#define DBG_FLASH_REDRAW 0

const int SPKR = 3;
#define BATT_CAL_VALUE 1.56923 // How many ticks of internal voltmeter per millivolt of battery
#define VUSB_CAL_VALUE 0.81769 // ... of USB voltage
#define BATT_LVC_WARN 3580 // Battery millivolts where game warns of low battery
#define BATT_LVC_REFUSE 3420 // Battery millivolts where game refuses to start
#define BATT_LVC_SHUTDOWN 3250 // Battery millivolts where game shuts off forcibly
#define BATT_LVC_IGNORE 1000 // Below this voltage, ignore battery
#define BATT_HVC_FULL 4100 // Battery stops charging at this voltage
#define BATT_HVC_EMPTY 4010 // Battery resumes charging at this voltage
#define USB_VOLTAGE_CHARGE 4000 // If USB at this level or more, attempt to charge battery
#define INSTANT_PROGRAMMING_BOARD_SIZE 10
bool LVCEN = false;

// Serial data bus for LEDs
#define SDA_PORT PORTC
const int SDA_INTERNAL = A0;
const int SDA_TF1_OFFENSE = A1;
const int SDA_TF1_DEFENSE = A2;
const int SDA_TF2_OFFENSE = A3;
const int SDA_TF2_DEFENSE = A4;
#define BOARD_TF1_OFFENSE 0
#define BOARD_TF1_DEFENSE 1
#define BOARD_TF2_OFFENSE 2
#define BOARD_TF2_DEFENSE 3
const int CHGEN = A5;
#define SEN_LED_PORT PORTB
#define SEN_LED_DDR DDRB
#define SLT_LED_PORT PORTD
#define SLT_LED_DDR DDRD
#define SCK_LED_PORT PORTC
#define SCK_LED_DDR PORTC
#define SEN_LED_PIN 1
#define SLT_LED_PIN 2
#define SCK_LED_PIN 5
#define BTNK_PORT PIND
#define BTNK_11 4
#define BTNK_12 5
#define BTNK_21 6
#define BTNK_22 7

#define INTER_SND_DELAY 250
#define SND_INIT 0
#define SND_PREPARE_FOR_BATTLE 1
#define SND_SELECT 2
#define SND_GAME 3
#define SND_ONE 4
#define SND_TWO 5
#define SND_THREE 6
#define SND_FOUR 7
#define SND_PLAYERS 8
#define SND_TASK_FORCE 9
#define SND_ENTER 10
#define SND_PATROL_BOAT 11
#define SND_LETTER 12
#define SND_NUMBER 13
#define SND_DIRECTION 14
#define SND_ARMED 15
#define SND_DESTROYER 16
#define SND_SUBMARINE 17
#define SND_BATTLESHIP 18
#define SND_CARRIER 19
#define SND_MISSILE_FIRED 20
#define SND_MISSILE_IMPACT 21
#define SND_SUNK 22
#define SND_HIT 23
#define SND_SIREN 24
#define SND_MAN_YOUR_BATTLE_STATIONS 25
#define SND_TAPS 26
#define SND_BUTTON 27
#define SND_FIRE 28
#define SND_SIZE 29
#define SND_SKILL 30
#define SND_NYAN 69
#define SND_BATTERY 31
#define SND_LOW 32
#define SND_DEPLETED 33

#define GFX_TYPE_CROSSHAIR 0
#define GFX_TYPE_HIT 1
#define GFX_TYPE_TWINKLE 2
#define GFX_TYPE_KABOOM 8

#define TYPE_PATROL_BOAT 1
#define TYPE_DESTROYER 2
#define TYPE_SUBMARINE 3
#define TYPE_BATTLESHIP 4
#define TYPE_CARRIER 5
#define TYPE_WHITEPEG 6
#define TYPE_REDPEG 7

#define DIR_NORTH 1
#define DIR_SOUTH 2
#define DIR_EAST 3
#define DIR_WEST 4

#define STATUS_FLEET_SUNK 2
#define STATUS_SHIP_SUNK 1


AsyncAnalog BattVoltage(A6);
AsyncAnalog USBVoltage(A7);
byte sndBuf[512];
byte ioBuf[48 * 12 * 2]; // 48 bytes * 12 rows * 2 bits of brightness
volatile uint16_t TF1BTND = 0;
volatile uint16_t TF2BTND = 0;
bool SNDEN = false;
bool SNDDIV = false;
volatile uint32_t MILLIS = 0;
volatile int sndReadPtr = 0;
volatile int sndWritePtr = 0;

void setup() {
  // Prevent bug where reboot occurred instead of shutdown due to capacitors not fully discharging
  _delay_ms(100);
  // Set pins
  pinMode(SPKR, OUTPUT);
  pinMode(SDA_INTERNAL, OUTPUT);
  pinMode(SDA_TF1_OFFENSE, OUTPUT);
  pinMode(SDA_TF1_DEFENSE, OUTPUT);
  pinMode(SDA_TF2_OFFENSE, OUTPUT);
  pinMode(SDA_TF2_DEFENSE, OUTPUT);
  pinMode(CHGEN, OUTPUT);
  // Set pins that aren't Arduino pins
  SEN_LED_DDR |= (1 << SEN_LED_PIN);
  SLT_LED_DDR |= (1 << SLT_LED_PIN);
  SCK_LED_DDR |= (1 << SCK_LED_PIN);

  // Set up speaker
  analogWrite(SPKR, 127);
  pinMode(3, OUTPUT);

  // Initialize I/O buffer
  initIoBuf();

  // Disable Timer2 so it doesn't cause jitter (flickering / distorted sound)
  noInterrupts();
  TCCR0A = 0;
  TCCR0B = 0;

  // Set Timer2 prescale to 0 for fast PWM
  // Timer2 is used to generate a class D speaker signal
  TCCR2A = _BV(COM2A0) | _BV(COM2B1) | _BV(WGM21) | _BV(WGM20);
  TCCR2B = _BV(WGM22) | _BV(CS20);
  OCR2A = 255; // 8 bit PWM
  OCR2B = 40; // 50% duty cycle to start

  // Set Timer1 for 16KHz system clock
  TCCR1A = TCCR1B = TCNT1 = 0;
  // Set compare match register
  OCR1A = 122;
  // turn on CTC mode
  TCCR1B |= (1 << WGM12);
  // Set bits for 8 prescaler
  TCCR1B |= (1 << CS11);
  // enable timer compare interrupt
  TIMSK1 |= (1 << OCIE1A);
  interrupts();

  // Initialize SPI for interfacing with flash chip
  SPI.begin();
  SPI.setClockDivider(SPI_CLOCK_DIV2); // Full speed
  SPI.setDataMode(0);
  SPI.setBitOrder(MSBFIRST);

  // Check for on button pressed. If off and plugged in, go to charge mode
  bool onBtnDet = false;
  for (byte x = 0; x < 100; x++) {
    if (pwrBtnPressed())
      onBtnDet = true;
    delay(5);
  }
  if (!onBtnDet && getBattLevel() > BATT_LVC_IGNORE * BATT_CAL_VALUE) {
    chargeMode();
  }
  delay(500);
  // Display bar graph of battery
  int lvl = map(getBattLevel() / BATT_CAL_VALUE, BATT_LVC_REFUSE, BATT_HVC_EMPTY, 0, 12);
  for (int x = 0; x < 12; x++) {
    setLED(BOARD_TF1_OFFENSE, 0, x, x < lvl ? B001100 : B110000);
  }
  while (true) { // Hold down TF1/A1 button when power on to access serial config mode
    // TODO if ON button not detected, go to charging mode
    if (TF1BTND == 1) {
      Serial.begin(19200);
      configMode();
    }
    if (MILLIS > 2000)
      break;
  }

  if (getBattLevel() > BATT_LVC_IGNORE * BATT_CAL_VALUE) {
    // Warn if battery too low
    if (getBattLevel() < (BATT_LVC_REFUSE * BATT_CAL_VALUE)) {
      sndPlaySynchronous(SND_BATTERY);
      delay(INTER_SND_DELAY / 2);
      sndPlaySynchronous(SND_DEPLETED);
      delay(INTER_SND_DELAY / 2);
      off();
    }

    if (getBattLevel() < (BATT_LVC_WARN * BATT_CAL_VALUE)) {
      sndPlaySynchronous(SND_BATTERY);
      delay(INTER_SND_DELAY / 2);
      sndPlaySynchronous(SND_LOW);
      delay(INTER_SND_DELAY);
    }
  }

  LVCEN = true; // Enable low voltage shutoff
}

void loop() {
  byte game = 0;
  byte players = 0;
  byte boardSize = 0;
  // Clear the game
  clearRam();
  clearLEDs();

  //  game = 2;
  //  players = 2;
  //  placeShip(1, 1, DIR_SOUTH, 0, 2, TYPE_PATROL_BOAT);
  //  placeShip(7, 7, DIR_SOUTH, 0, 3, TYPE_DESTROYER);
  //  placeShip(1, 1, DIR_SOUTH, 1, 2, TYPE_PATROL_BOAT);
  //  placeShip(7, 7, DIR_SOUTH, 1, 3, TYPE_DESTROYER);
  //  gfxRedrawAll();
  //  goto XXX_SKIP_ENTRY;

  //  game = 2;
  //  players = 2;
  //  boardSize = 10;
  //  goto XXX_SKIP_INTRO;

  // TODO warn user if battery is low

  sndPlay(SND_INIT); // ---------------- PREPARE FOR BATTLE
  while (SNDEN)
    sndService();
  delay(INTER_SND_DELAY);


  sndPlay(SND_PREPARE_FOR_BATTLE);
  while (SNDEN)
    sndService();

  boardSize = 0;
  do { // ---------------- SELECT SIZE
    delay(INTER_SND_DELAY);
    sndPlaySynchronous(SND_SELECT);
    delay(INTER_SND_DELAY / 2);
    sndPlay(SND_SIZE);
    boardSize = getTfxNumBlocking(0);
    randomSeed(random() + Millis());
  }
  while (boardSize < 8 || boardSize == 13);
  gfxSetCrosshair(15, 15); // Show the game size
  gfxSetBoardSize(boardSize);
  gfxSetDirection(0, 0);
  gfxSetType(GFX_TYPE_CROSSHAIR);
  gfxRedraw(getDefensiveBoard(0)); // Draw onto TF1 DEFENSE
  while (SNDEN)
    sndService();
  delay(INTER_SND_DELAY);

  game = 0;
  do { // ---------------- SELECT GAME
    while (SNDEN)
      sndService();
    delay(INTER_SND_DELAY);
    sndPlaySynchronous(SND_SELECT);
    delay(INTER_SND_DELAY / 2);
    sndPlay(SND_GAME);
    game = getTfxNumBlocking(0);
    randomSeed(random() + Millis());
    if (game == 12)
      easterEggNyanCat();
    if (game == 11)
      easterEggDBG();
    if (game == 10)
      easterEggDBG2();
  }
  while (game == 0 || game > 4);
  while (SNDEN)
    sndService();
  delay(INTER_SND_DELAY);

  sndPlaySynchronous(SND_GAME);  // ---------------- ANNOUNCE GAME SELECTION
  delay(INTER_SND_DELAY / 2);
  sndPlaySynchronous(SND_ONE + (game - 1));
  delay(INTER_SND_DELAY);

  if (game == 4) { // Game 4 is for 2 players only. Players decide on their own firing rules
    players = 2;
  } else {
    players = 0;
    do { // ---------------- SELECT PLAYERS
      while (SNDEN)
        sndService();
      delay(INTER_SND_DELAY);
      sndPlaySynchronous(SND_SELECT);
      delay(INTER_SND_DELAY / 2);
      sndPlay(SND_PLAYERS);
      players = getTfxNumBlocking(0);
    }
    while (players == 0 || players > 2);
    while (SNDEN)
      sndService();
    delay(INTER_SND_DELAY / 2);
    sndPlaySynchronous(SND_ONE + (players - 1));
    delay(INTER_SND_DELAY);
  }


XXX_SKIP_INTRO:
  for (int x = 0; x < players; x++) { // ---------------- PROGRAMMING
    bool needsManual = true;
    if (boardSize == INSTANT_PROGRAMMING_BOARD_SIZE) { // Instant programming entry
      do {
        sndPlaySynchronous(SND_TASK_FORCE);
        delay(INTER_SND_DELAY / 4);
        sndPlaySynchronous(SND_ONE + x);
        delay(INTER_SND_DELAY / 4);
        sndPlaySynchronous(SND_ENTER);
        delay(INTER_SND_DELAY / 4);
        sndPlaySynchronous(SND_LETTER);
        delay(INTER_SND_DELAY / 4);
        sndPlay(SND_NUMBER);

        byte pLetter = boardSize == INSTANT_PROGRAMMING_BOARD_SIZE ? getTfxNumBlocking(x) : 13;
        if (pLetter <= 10) { // Instant programming
          byte pNumber = getTfxNumBlocking(x);
          if (getTfxNumBlocking(x) == 13) {
            if (pNumber <= 10) {
              needsManual = false;
              placeShipsInstant(x, pLetter, pNumber);
              gfxSetBoardSize(255);
              gfxSetCrosshair(15, 15); // Clear entry crosshairs and direction and display ships
              gfxSetDirection(0, 0);
              gfxRedraw(getDefensiveBoard(x));
              gfxSetBoardSize(boardSize);
              break;
            }
          }
        }
        else if (pLetter == 13) break; // Exit for manual programming
      } while (true);
    }

    if (needsManual) { // Manual programming
      sndPlaySynchronous(SND_TASK_FORCE);
      delay(INTER_SND_DELAY / 4);
      sndPlaySynchronous(SND_ONE + x);
      delay(INTER_SND_DELAY / 4);
      bool needsLND = true;
      for (int y = 0; y < 5; y++) {
        do {
          gfxSetCrosshair(15, 15); // Clear entry crosshairs and direction
          gfxSetDirection(0, 0);
          gfxSetBoardSize(boardSize);
          gfxSetType(GFX_TYPE_CROSSHAIR);
          gfxRedraw(getDefensiveBoard(x));

          sndPlaySynchronous(SND_ENTER);
          delay(INTER_SND_DELAY / 4);
          sndPlaySynchronous(getBoatSound(y));
          if (needsLND) {
            delay(INTER_SND_DELAY / 4);
            sndPlaySynchronous(SND_LETTER);
            delay(INTER_SND_DELAY / 4);
            sndPlaySynchronous(SND_NUMBER);
            delay(INTER_SND_DELAY / 4);
            sndPlaySynchronous(SND_DIRECTION);
            needsLND = false;
          }
          byte letter = getTfxNumBlocking(x);
          if (letter == 13) {
            needsLND = true;
            continue;
          }
          gfxSetCrosshair(15, letter - 1);
          gfxRedraw(getDefensiveBoard(x));
          byte number = getTfxNumBlocking(x);
          if (number == 13) {
            needsLND = true;
            continue;
          }
          gfxSetCrosshair(number - 1, letter - 1);
          gfxRedraw(getDefensiveBoard(x));
          byte direction = getTfxNumBlocking(x);
          if (direction == 13) {
            needsLND = true;
            continue;
          }
          gfxSetDirection(direction, getBoatLength(y + 1));
          gfxRedraw(getDefensiveBoard(x));
          byte enter = getTfxNumBlocking(x);
          delay(INTER_SND_DELAY);
          if (enter == 13 && placeShipConstrained(boardSize, letter, number, direction, x, getBoatLength(y + 1), y + 1)) {
            break;
          } else {
            needsLND = true;
          }
        }
        while (true);

        gfxSetCrosshair(15, 15); // Clear entry crosshairs and direction. This also displays new ship
        gfxSetDirection(0, 0);
        gfxRedraw(getDefensiveBoard(x));

        sndPlaySynchronous(getBoatSound(y));
        delay(INTER_SND_DELAY * 3 / 4);
        sndPlaySynchronous(SND_ARMED);
        delay(INTER_SND_DELAY);
      } // End ship entry loop

      // Clear the board size mask from the current player's entry field
      gfxSetBoardSize(255);
      gfxRedraw(getDefensiveBoard(x));
      gfxSetBoardSize(boardSize);

    } // End manual programming
    //    while (true) {
    //      sndService(); // TODO XXX
    //    }
    while (SNDEN) {
      sndService();
    }
    sndPlaySynchronous(SND_TASK_FORCE);
    delay(INTER_SND_DELAY / 4);
    sndPlaySynchronous(SND_ONE + x);
    delay(INTER_SND_DELAY * 3 / 4);
    sndPlaySynchronous(SND_ARMED);
    delay(INTER_SND_DELAY * 3 / 2);
  } // End programming
  sndPlaySynchronous(SND_SIREN);
  delay(INTER_SND_DELAY / 4);
  sndPlaySynchronous(SND_MAN_YOUR_BATTLE_STATIONS);
  delay(INTER_SND_DELAY * 3 / 2);

XXX_SKIP_ENTRY:
  gfxSetBoardSize(255);

  byte needsELNF = 0x03; // H = TaskForce2, L = TaskForce1
  byte turn = 0; // 0 for TF1, 1 for TF2
  bool omitFiringInstructions = false; // Works for the next firing only
  byte g3ShotsRemaining = 2; // Start with 3 shots instead of 5, for fairness. Number is (#shots - 1) because no turn check
  if (game == 4) { // Announce start of game 4, no instructions given otherwise
    sndPlaySynchronous(SND_FIRE);
  }
  while (true) { // ---------------- MAIN GAME
    gfxSetCrosshair(15, 15);
    gfxRedraw(getOffensiveBoard(turn));

    if (!omitFiringInstructions && game != 4) {
      sndPlaySynchronous(SND_TASK_FORCE);
      delay(INTER_SND_DELAY / 4);
      sndPlaySynchronous(SND_ONE + turn);
      delay(INTER_SND_DELAY / 4);
      if (bitRead(needsELNF, turn)) {
        bitWrite(needsELNF, turn, 0);
        delay(INTER_SND_DELAY / 4);
        sndPlaySynchronous(SND_ENTER);
        delay(INTER_SND_DELAY / 4);
        sndPlaySynchronous(SND_LETTER);
        delay(INTER_SND_DELAY / 4);
        sndPlaySynchronous(SND_NUMBER);
        delay(INTER_SND_DELAY / 4);
      }
      sndPlay(SND_FIRE);
    }
    byte letter, number;
    if (players == 1 && turn == 1) { // Computer turn
      byte res = computerTurn(
    }

    else { // Human turn with prompting and stuff
      omitFiringInstructions = false;
      letter = getTfANumBlocking();
      if (game == 4) { // On game 4, whoever pushes the button has the turn
        turn = (letter >> 7) & 1;
      }
      if (letter == 13 || ((letter >> 7) & 1) != turn) {
        bitWrite(needsELNF, turn, 1);
        continue;
      }
      letter &= 0x77; // Cut off the high bit, it represents turn, not number

      gfxSetType(GFX_TYPE_CROSSHAIR);
      gfxSetCrosshair(15, letter - 1);
      gfxRedraw(getOffensiveBoard(turn));

      number = getTfxNumBlocking(turn);
      if (number == 13) {
        bitWrite(needsELNF, turn, 1);
        continue;
      }
      gfxSetCrosshair(number - 1, letter - 1);
      gfxRedraw(getOffensiveBoard(turn));

      byte enter = getTfxNumBlocking(turn);
      if (enter != 13) {
        bitWrite(needsELNF, turn, 1);
        continue;
      }
      gfxSetCrosshair(15, 15);
      gfxRedraw(getOffensiveBoard(turn));
    }

    // Fire the missile
    while (SNDEN)
      sndService();
    delay(INTER_SND_DELAY / 2);
    byte shotResult = fire(letter, number, turn ? 0 : 1);
    sndPlay(SND_MISSILE_FIRED);
    gfxSetType(GFX_TYPE_TWINKLE);
    while (SNDEN) { // Missile lights
      gfxSetCrosshair(number - 1, letter - 1);
      gfxRedraw(getOffensiveBoard(turn));
      sndService();
      byte sndProg = sndProgress();
      setMainLED(0, random(0, 255 - sndProg) / 2, random(0, sndProg) / 2, turn);
    }
    gfxSetType(GFX_TYPE_CROSSHAIR);
    gfxSetCrosshair(15, 15);

    gfxRedraw(getOffensiveBoard(turn));
    if (!isShipType(shotResult)) // Only redraw on miss as to not prematurely show hit
      gfxRedraw(getDefensiveBoard(turn ? 0 : 1));
    clearMainLEDs();
    if (isShipType(shotResult)) {
      delay(INTER_SND_DELAY / 2);
      sndPlay(SND_MISSILE_IMPACT);
      while (SNDEN) { // Ship hit lights
        sndService();
        int loudVal = sndLoudness() / 50;
        byte r = min(loudVal, 255);
        byte g = constrain(loudVal - 255, 0, 180);
        byte b = constrain(loudVal - 265, 0, 103);
        setMainLED(r, g, b, turn);
        setMainLED(r, g, b, turn ? 0 : 1);
        gfxSetType(GFX_TYPE_KABOOM);
        gfxSetDirection(0, loudVal / 65);
        gfxSetCrosshair(number - 1, letter - 1);
        gfxRedraw(getOffensiveBoard(turn));
        sndService();
        gfxRedraw(getDefensiveBoard(turn ? 0 : 1));
      }
      setMainLEDs(0, 0, 0, 0, 0, 0);
      gfxSetCrosshair(15, 15);
      gfxSetType(GFX_TYPE_CROSSHAIR);
      gfxRedraw(getOffensiveBoard(turn));
      gfxRedraw(getDefensiveBoard(turn ? 0 : 1));
      delay(INTER_SND_DELAY);

      byte oppStatus = getTaskForceStatus(shotResult, turn ? 0 : 1);
      if (oppStatus == STATUS_FLEET_SUNK) {
        sndPlaySynchronous(getBoatSound(shotResult - 1));
        delay(INTER_SND_DELAY * 3 / 4);
        sndPlaySynchronous(SND_SUNK);
        delay(INTER_SND_DELAY);
        break; // End game
      }
      else {
        sndPlaySynchronous(getBoatSound(shotResult - 1));
        delay(INTER_SND_DELAY * 3 / 4);
        if (oppStatus == STATUS_SHIP_SUNK)
          sndPlaySynchronous(SND_SUNK);
        else
          sndPlaySynchronous(SND_HIT);
      }
      if (game == 2) {
        turn = (turn) ? 0 : 1; // Skip opponent turn when you are playing game 2 and hit a ship
        omitFiringInstructions = true; // And tell the other player...
      }
    }
    if (game == 3) {
      if (g3ShotsRemaining > 0) {
        g3ShotsRemaining--;
        turn = (turn) ? 0 : 1; // Skip opponent turn when you are playing game 3 and have shots remaining
        omitFiringInstructions = true; // And tell the other player...
      }
      else { // Out of shots. Calculate shots for next turn
        g3ShotsRemaining = countRemainingShips(turn ? 0 : 1) - 1;
      }
    }
    delay(INTER_SND_DELAY * 5 / 2);

    turn = (turn) ? 0 : 1;
  }
  // ---------------- Game over. Play taps for the loser
  sndPlaySynchronous(SND_SIREN);
  delay(INTER_SND_DELAY * 3 / 2);
  sndPlaySynchronous(SND_TASK_FORCE);
  delay(INTER_SND_DELAY / 4);
  sndPlaySynchronous(SND_ONE + (turn ? 0 : 1));
  delay(INTER_SND_DELAY / 4);
  sndPlaySynchronous(SND_SUNK);
  delay(INTER_SND_DELAY * 3 / 2);
  sndPlaySynchronous(SND_TAPS);

  while (!pwrBtnPressed()) {
    sndService();
  }
  off();
}

// Looks at the field and decides where to fire.
// Return a byte consisting of LLLLNNNN (letter, number)
// Storage - pointer to a byte array used for memory - must be 4 bytes in size
// BoardSize - self-explanatory
// Skill - How good the computer is
//  0 = always fires A1
//  1 = random guessing
//  2 = pattern with random start
//  3 = intelligent pattern with cheated start
//  4 = intelligent pattern with cheated start and cheated following
byte computerTurn(byte* storage, byte boardSize, byte skill) {
  if (skill == 0)
    return 17;
  return (random(1, boardSize + 1) << 4) + random(1, boardSize + 1);
}



/**
  Determine whether a hit sunk the fleet, a ship, or was just a hit
*/
byte getTaskForceStatus(byte shotResult, byte plyr) {
  bool anyShipFound = false;
  for (byte x = 1; x <= 12; x++) {
    for (byte y = 1; y <= 12; y++) {
      byte res = readRam(getRamPtr(x, y, plyr));
      if (res == shotResult)
        return 0;
      if (res >= TYPE_PATROL_BOAT && res <= TYPE_CARRIER) {
        anyShipFound = true;
      }
    }
  }
  return anyShipFound ? STATUS_SHIP_SUNK : STATUS_FLEET_SUNK;
}

byte countRemainingShips(byte plyr) {
  byte shipCntr = 0;
  for (byte x = 1; x <= 12; x++) {
    for (byte y = 1; y <= 12; y++) {
      byte res = readRam(getRamPtr(x, y, plyr));
      if (res >= TYPE_PATROL_BOAT && res <= TYPE_CARRIER) {
        shipCntr |= (1 << (res - TYPE_PATROL_BOAT));
      }
    }
  }
  return countSetBits(shipCntr);
}


void placeShipsRandom(byte boardSz, byte player) {
  for (int x = 0; x < 5; x++) {
    while (true) {
      byte letter = random(boardSz) + 1;
      byte number = random(boardSz) + 1;
      byte direction = random(4) + 1;
      bool res = placeShipConstrained(boardSz, letter, number, direction, player, getBoatLength(x + TYPE_PATROL_BOAT), x + TYPE_PATROL_BOAT);
      if (res) // On successful ship placement, go to next ship
        break;
    }
  }
}

bool placeShipConstrained(byte boardSz, byte letter, byte number, byte direction, byte player, byte length, byte type) {
  if (letter > boardSz || number > boardSz)
    return false; // Ship start coord out of bounds
  if (direction < 1 || direction > 4)
    return false; // Invalid direction

  for (byte i = 0; i < 2; i++) {
    // First pass verify, second pass place
    for (byte x = 0; x < length; x++) {
      byte effLetter = getLetter(letter, direction, x);
      byte effNumber = getNumber(number, direction, x);
      if (i == 0 && effLetter < 1 || effNumber < 1 || effLetter > boardSz || effNumber > boardSz)
        return false; // Ship hangs off board
      int ramPtr = getRamPtr(effLetter, effNumber, player);
      byte existing = readRam(ramPtr);
      if (i == 0 && existing != 0) {
        return false; // Peg not empty
      }
      if (i == 1) {
        writeRam(ramPtr, type);
      }
    }
  }
  return true;
}

bool placeShip(byte letter, byte number, byte direction, byte player, byte length, byte type) {
  return placeShipConstrained(12, letter, number, direction, player, length, type);
}

byte getLetter(byte oLetter, byte direction, byte distance) {
  if (direction == DIR_NORTH)
    return oLetter - distance;
  if (direction == DIR_SOUTH)
    return oLetter + distance;
  return oLetter;
}
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

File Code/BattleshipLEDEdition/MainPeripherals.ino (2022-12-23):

byte TF1DBNC[13];
byte TF2DBNC[13];

/** I/O buffer structure
    Bit 0: Main peripherals
    Bit 1: Task Force 1 offense
    Bit 2: Task Force 1 defense
    Bit 3: Task force 2 offense
    Bit 4: Task force 3 defense

    Byte 0-8: LED K5 K6 K7 K8 K9 K10 K11 K12
    Byte 9-16: LED B9 B10 B11 B12 K1 K2 K3 K4
    Byte 17-24: LED B1 B2 B3 B4 B5 B6 B7 B8
    Byte 25-32: LED G5 G6 G7 G8 G9 G10 G11 G12
    Byte 33-40: LED R9 R10 R11 R12 G1 G2 G3 G4
    Byte 41-47: LED R1 R2 R3 R4 R5 R6 R7 R8

    MAIN PERIPHERALS: SPEN BTNA1 BTNA2 BTNA3 BTNA4 BTNA5 BTNA6 BTNA7 SPEN  BLU GRN RED TF1LEDEN TF2LEDEN PWRCTL CHGEN -
*/

void initIoBuf() {
  for (int x = 0; x < 13; x++) {
    TF1DBNC[x] = 127;
    TF2DBNC[x] = 127;
  }
  int i = 0;
  for (byte x = 0; x < 2; x++) { // 2 color bits
    for (byte y = 0; y < 12; y++) { // 12 rows
      for (byte z = 0; z < 48; z++) { // 48 physical bits
        if (z >= 33 && z < 40 && y < 7) { // Button drive wave
          ioBuf[i] = ((39 - z) == y) ? 1 : 0;
        }
        else if (z == 43 && !(y & 1) || (z == 44 & (y & 1))) { // Main LED drive wave
          ioBuf[i] = 1;
        }
        else if (z == 42) {
          ioBuf[i] = 1; // SMPS enable (PWRCTL)
        }
        else {
          ioBuf[i] = 0;
        }
        if (z == 11 - y) { // Cathode drive wave
          ioBuf[i] |= 30;
        }
        i++;
      }
    }
  }
}


uint16_t TF1BTN = 0;
uint16_t TF2BTN = 0;
uint16_t RSTCTR = 0;
uint16_t PWRCTR = 0;
volatile uint16_t BATTLVL = 0; // 0 - 8192 reading of battery voltage
volatile uint16_t USBVLVL = 0; // 0 - 8192 reading of USB voltage

inline void MPIsr() {
  static byte pRow = 255;
  static byte row = 0;
  static byte bit = 0;
  static byte frame = 0;
  static bool usbAnalogTurn = false;
  static bool battFullHyst = false;


  // Input
  if ((frame & 63) == 1) { // Battery voltage reading
    if (BattVoltage.ready()) {
      if (usbAnalogTurn) {
        USBVLVL = ((USBVLVL + USBVoltage.value()) / 9 ) * 8;
        BattVoltage.start();
      }
      else {
        BATTLVL = ((BATTLVL + BattVoltage.value()) / 9 ) * 8;
        USBVoltage.start();
        if (LVCEN && BATTLVL < BATT_LVC_SHUTDOWN * BATT_CAL_VALUE && BATTLVL > BATT_LVC_IGNORE * BATT_CAL_VALUE) {
          clearLEDs();
          shiftLed(ioBuf, 48); // Just to blank the display
          // TODO announce that the battery is depleted
          off(50);
        }
      }
      usbAnalogTurn = !usbAnalogTurn;
    }
  }

  if ((frame & 63) == 2) { // Handle battery charging
    if (BATTLVL > BATT_HVC_FULL * BATT_CAL_VALUE)
      battFullHyst = true;
    else if (BATTLVL < BATT_HVC_EMPTY * BATT_CAL_VALUE) // Charge set point hysteresis
      battFullHyst = false;

    if (USBVLVL > USB_VOLTAGE_CHARGE * VUSB_CAL_VALUE)
      PWRCTR = 0; // No power timeout if charging

    if (USBVLVL > USB_VOLTAGE_CHARGE * VUSB_CAL_VALUE && !battFullHyst) {
      setCharging(1);
    }
    else {
      setCharging(0);
    }
    //    setCharging(1);
  }

  if ((frame & 255) == 3) { // Handle power-off timeout
    if (!TF1BTN && !TF2BTN)
      PWRCTR++;
    else
      PWRCTR = 0;
    if (PWRCTR == 38400) // Warning tone after 10 minutes
      sndPlay(SND_TAPS);
    if (PWRCTR >= 42240) // Off after 11 minutes
      off();
  }

  if ((frame & 7) == 0) {
    if (pwrBtnPressed()) { // Reboot / Power off button hold counter
      RSTCTR++;
      if (RSTCTR >= 5000) {
        off();
      }
    }
    else {
      RSTCTR = 0;
    }
    if (pRow < 7) { // Read buttons into TFxBTNP variables
      bitWrite(TF1BTN, pRow, bitRead(BTNK_PORT, BTNK_11));
      bitWrite(TF1BTN, pRow + 7, bitRead(BTNK_PORT, BTNK_12));
      bitWrite(TF2BTN, pRow, bitRead(BTNK_PORT, BTNK_21));
      bitWrite(TF2BTN, pRow + 7, bitRead(BTNK_PORT, BTNK_22));
    }
    byte x = pRow;
    if (bitRead(TF1BTN, x)) {
      if (TF1DBNC[x] < 132)
        TF1DBNC[x]++;
      else
        bitWrite(TF1BTND, x, 1);
    }
    else {
      if (TF1DBNC[x] > 120)
        TF1DBNC[x]--;
      else
        bitWrite(TF1BTND, x, 0);
    }
    if (bitRead(TF2BTN, x)) {
      if (TF2DBNC[x] < 132)
        TF2DBNC[x]++;
      else
        bitWrite(TF2BTND, x, 1);
    }
    else {
      if (TF2DBNC[x] > 120)
        TF2DBNC[x]--;
      else
        bitWrite(TF2BTND, x, 0);
    }
    if (x == 10)
      bitWrite(TF1BTND, 12, bitRead(TF1BTN, 12));
    if (x == 11)
      bitWrite(TF2BTND, 12, bitRead(TF2BTN, 12));
  }

  // Output
  int idx = row * 48;
  if (bit != 0)
    idx += (48 * 12);
  byte* ptr = &ioBuf[idx];
  shiftLed(ptr, 48);

  // Update state
  pRow = row;
  row++;
  if (row > 11) {
    row = 0;
    bit++;
    frame++;
    if (bit > 2)
      bit = 0;
  }
}

inline void shiftLed(byte * value, byte len) {
  bitWrite(SLT_LED_PORT, SLT_LED_PIN, 0);
  bitWrite(SCK_LED_PORT, SCK_LED_PIN, 0);
  byte lenm1 = len - 8;
  for (byte x = 0; x < len; x += 8) { // Loop unrolled for performance reasons
    SDA_PORT = value[x] & B00011111;
    bitWrite(SCK_LED_PORT, SCK_LED_PIN, 1);
    if (x == lenm1)
      bitWrite(SEN_LED_PORT, SEN_LED_PIN, 1);
    SDA_PORT = value[x + 1] & B00011111;
    bitWrite(SCK_LED_PORT, SCK_LED_PIN, 1);
    SDA_PORT = value[x + 2] & B00011111;
    bitWrite(SCK_LED_PORT, SCK_LED_PIN, 1);
    SDA_PORT = value[x + 3] & B00011111;
    bitWrite(SCK_LED_PORT, SCK_LED_PIN, 1);
    SDA_PORT = value[x + 4] & B00011111;
    bitWrite(SCK_LED_PORT, SCK_LED_PIN, 1);
    SDA_PORT = value[x + 5] & B00011111;
    bitWrite(SCK_LED_PORT, SCK_LED_PIN, 1);
    SDA_PORT = value[x + 6] & B00011111;
    bitWrite(SCK_LED_PORT, SCK_LED_PIN, 1);
    SDA_PORT = value[x + 7] & B00011111;
    bitWrite(SCK_LED_PORT, SCK_LED_PIN, 1);
  }
  bitWrite(SLT_LED_PORT, SLT_LED_PIN, 1);
  bitWrite(SEN_LED_PORT, SEN_LED_PIN, 0);
}

/**
   Set the color of the board LEDs
   The resolution of these LEDs is 2 bits per color, or 6 bits per pixel.
   Due to read-optimization of the internal data structure this function is slow
   @param boardId ID of LED board to set pixel on
   @param x, y Coordinates of LED
   @param color 6-bit color, as byte (00 RR GG BB)
*/
void setLED(byte boardId, byte y, byte x, byte color) {
  uint16_t baseAddr = y * 48 + (11 - x);
  boardId++;
  // Red low
  bitWrite(ioBuf[baseAddr + 12], boardId, (color >> 4) & 1);
  // Red high
  bitWrite(ioBuf[576 + baseAddr + 12], boardId, (color >> 5) & 1);

  // Green low
  bitWrite(ioBuf[baseAddr + 24], boardId, (color >> 2) & 1);
  // Green high
  bitWrite(ioBuf[576 + baseAddr + 24], boardId, (color >> 3) & 1);

  // Blue low
  bitWrite(ioBuf[baseAddr + 36], boardId, (color >> 0) & 1);
  // Blue high
  bitWrite(ioBuf[576 + baseAddr + 36], boardId, (color >> 1) & 1);
}


void clearLEDs() {
  clearLEDs(0x0F);
}
void clearLEDs(byte boardMask) {
  boardMask &= 0x0F;
  boardMask = boardMask << 1;
  boardMask = ~boardMask;
  for (uint16_t x = 0; x < 2 * 12 * 48; x++) {
    if (x % 48 >= 12)
      ioBuf[x] &= boardMask;
  }
}
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

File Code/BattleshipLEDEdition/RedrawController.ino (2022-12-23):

//#define GFX_TYPE_CROSSHAIR 0
//#define GFX_TYPE_HIT 1
//#define GFX_TYPE_TWINKLE 2
//#define GFX_TYPE_KABOOM 8

byte GFXDRAWTYPE = 0; // 0 = Crosshair, 1 = hit, 2 = Twinkle...
byte GFXCROSSHAIR = 0xFF; // B XXXX YYYY for ship entry / hit crosshair
byte GFXDIRECTION = 0; // B LLLLL (Length)  NNN (NONE NORTH SOUTH EAST WEST NONE NONE NONE)
byte GFXBOARDSIZE = 255; // Overlay indicating playable game size. Set to 255 to hide
byte GFXDRAWFLAGS = 0; // // B 0000 000P // P=1 disables task force 2 for 1 player mode

void gfxRedrawAll() {
  gfxRedraw(0);
  gfxRedraw(1);
  gfxRedraw(2);
  gfxRedraw(3);
}

void gfxRedraw(byte board) {
  if (DBG_FLASH_REDRAW) {
    for (byte x = 0; x < 12; x++) {
      for (byte y = 0; y < 12; y++) {
        setLED(board, x, y, B111111);
      }
    }
    Delay(20);
  }

  if (board == BOARD_TF1_DEFENSE || board == BOARD_TF2_DEFENSE) {
    for (byte x = 0; x < 12; x++) {
      for (byte y = 0; y < 12; y++) {
        setLED(board, x, y, gfxShader(board, x, y, true));
      }
    }
  }
  else if (board == BOARD_TF1_OFFENSE || board == BOARD_TF2_OFFENSE) {
    for (byte x = 0; x < 12; x++) {
      for (byte y = 0; y < 12; y++) {
        setLED(board, x, y, gfxShader(board, x, y, false));
      }
    }
  }
}

inline byte gfxShader(byte board, byte x, byte y, bool drawShips) {
  // Blocker layer (always on top)
  if(GFXDRAWFLAGS & 1 && (board == BOARD_TF2_OFFENSE || board == BOARD_TF2_DEFENSE)){
    return 0;
  }
  // Crosshair layer
  byte crossX = (GFXCROSSHAIR & 0x0F);
  byte crossY = ((GFXCROSSHAIR & 0xF0) >> 4);
  byte kaboomClose = 0;
  if (GFXDRAWTYPE == GFX_TYPE_KABOOM) {
    kaboomClose = (GFXDIRECTION >> 3) - (abs(x - crossX) + abs(y - crossY) + max(abs(x - crossX), abs(y - crossY))) / 2 + ((x + y) & 1);
  }

  if (GFXBOARDSIZE != 255 && ((x == GFXBOARDSIZE && y <= GFXBOARDSIZE) || (y == GFXBOARDSIZE && x <= GFXBOARDSIZE))) {
    return B010101; // Board size layer
  }

  else if (GFXBOARDSIZE != 255 && (x > GFXBOARDSIZE || y > GFXBOARDSIZE)) {
    return B000000; // Board size mask
  }

  if (GFXDRAWTYPE == GFX_TYPE_KABOOM && kaboomClose < 127) { // AKA greater than 0 signed   // KABOOM! Layer
    if (kaboomClose < 1)
      return B010000;
    if (kaboomClose < 3)
      return B110000;
    if (kaboomClose < 4)
      return B110100;
    if (kaboomClose < 6)
      return B111100;
    return B111111;
  }

  else if (x == crossX && y == crossY) {
    if (GFXDRAWTYPE == GFX_TYPE_TWINKLE)
      return Millis() & 1 ? B001101 : B000111;
    else
      return B111111;
  }

  else if (GFXDRAWTYPE == GFX_TYPE_CROSSHAIR && (x == crossX || y == crossY)) {
    byte dir = (GFXDIRECTION & 7);
    byte dirLen = (GFXDIRECTION >> 3);
    if ((dir == DIR_NORTH && (x < crossX && x > crossX - dirLen)) ||
        (dir == DIR_SOUTH && (x > crossX && x < crossX + dirLen)) ||
        (dir == DIR_WEST && (y < crossY && y > crossY - dirLen)) ||
        (dir == DIR_EAST && (y > crossY && y < crossY + dirLen)))
      return B111111;
    else if (crossX == 15 || crossY == 15)
      return B000101;
  }
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
